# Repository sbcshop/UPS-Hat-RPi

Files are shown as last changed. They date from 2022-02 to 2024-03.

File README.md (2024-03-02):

# UPS-Hat-for-Raspberry-Pi
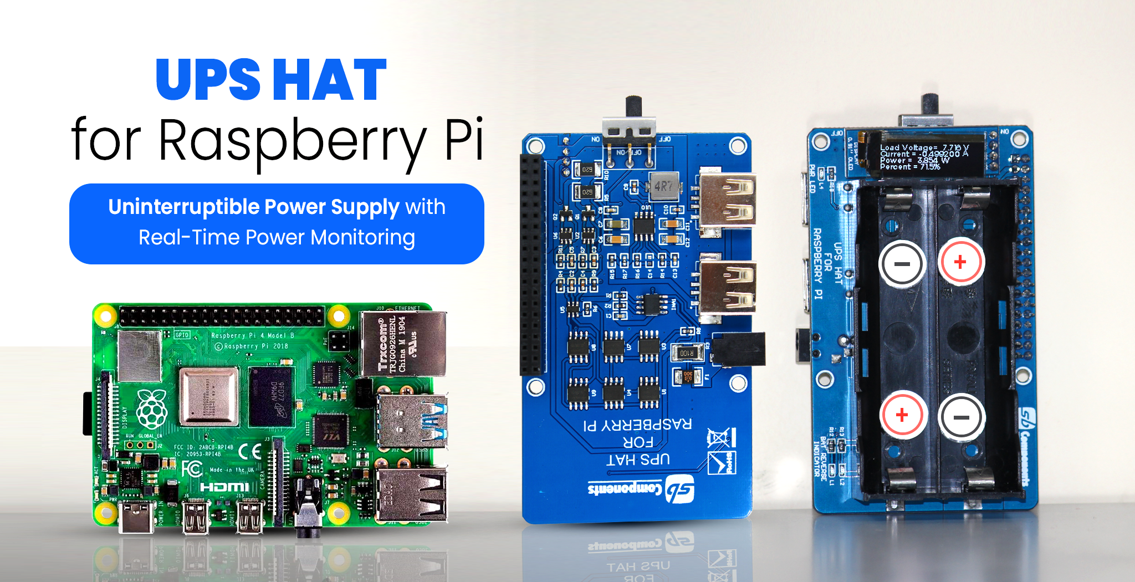
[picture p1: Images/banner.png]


## UPS Hat is a 5v power supply, It fit at the top of the raspberry pi, it gives power backup, while raspberry pi's USB power is cut off. It has various protections like short circuit protection, reverse battery protection and indicator, overcharge/discharge protection, and over current protection. It has a 5V USB output, convenient for powering other boards.
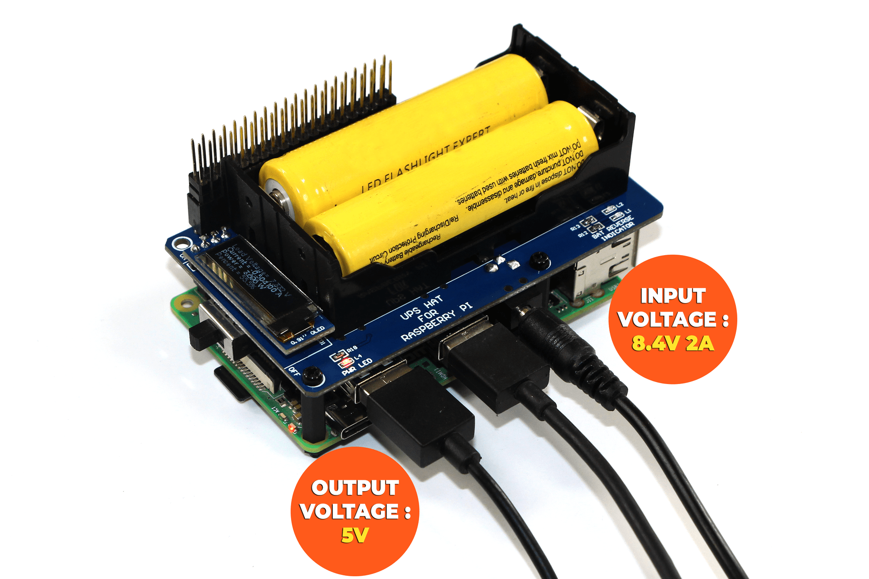
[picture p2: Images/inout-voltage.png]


## Features
  * Two on board battery reverse indicator Led's 
  * Two on board USB power port for external devices
  * Onboard oled display, for displaying current, voltage,power and battery percentage of UPS HAT
  * Onboard Battery Pack Protection and Charge Balance IC 

## Specification:-
- **Output voltage :** 5V USB 
- **Charger :** 8.4V 2A (Recommended)
- **Commuincation :** I2C 
- **Power monitoring IC :** INA219
- **Battery Supported :** 18650 Li Battery
- Display=>
 	* **Type** : OLED
 	* **Screen Size** : 0.91"
 	* **Resolution** : 128x32 pixels
 	* **Color** : Monochrome
	 * **Interface** : I2C
    
## Code
### First of all, you need to enable I2C in raspberry pi, for this you need to go  ```sudo raspi-config ``` then go to "interface options->I2C->yes->press enter" 
### This folder contains two python files and Images, Fonts folder:-
   * **INA219_UPS.py**  -> This file you need to run, displays the load voltage, current, power, and battery percentage on the terminal as well as in OLED
   * **oled_091.py**    ->This is the OLED display library 
   * **Images folder** contains images which we display in OLED display
   * **Fonts folder** contain various fonts, which we use in the OLED display
   
## Steps To Use UPS HAT (Follow These Steps) (**Important** *)
### Connect the type c power to the raspberry pi first, then turn on the UPS HAT, then disconnect the type c power from the raspberry pi or turn off the raspberry pi external power (at this time raspberry pi restart due to sudden power drop)Then reconnect the type c power to the Raspberry Pi after that ( In this process your raspberry pi needs to restart one time if you use UPS backup), The Raspberry Pi now does not restart if the type c power is turned off or if the external power is turned off.
### You need to follow this process when you use UPS HAT. if you use this process, your OLED problem is also resolved(static noise pattern)

  * Fix UPS HAT at the top of the Raspberry Pi
  
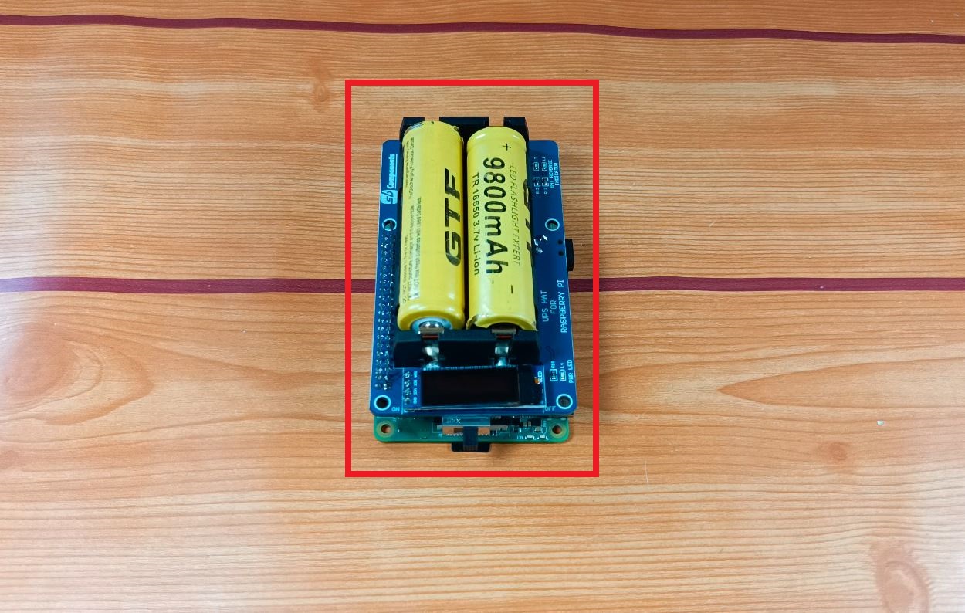
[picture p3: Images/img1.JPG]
    
   
  * Plug the Power cable to raspberry pi

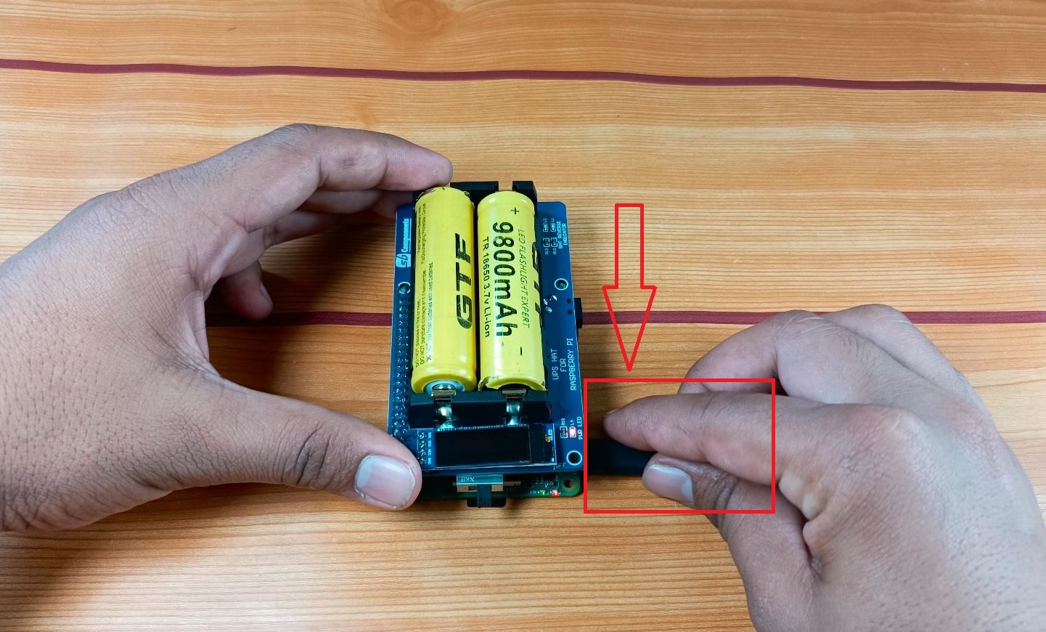
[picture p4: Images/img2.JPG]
    
    
  * Now Switch on UPS HAT using slider switch,then disconnect the type c power from the raspberry pi or turn off the raspberry pi external power (at this time             raspberry pi restart due to sudden power drop)Then reconnect the type c power to the Raspberry Pi after that ( In this process your raspberry pi needs to restart       one time if you use UPS backup)
  
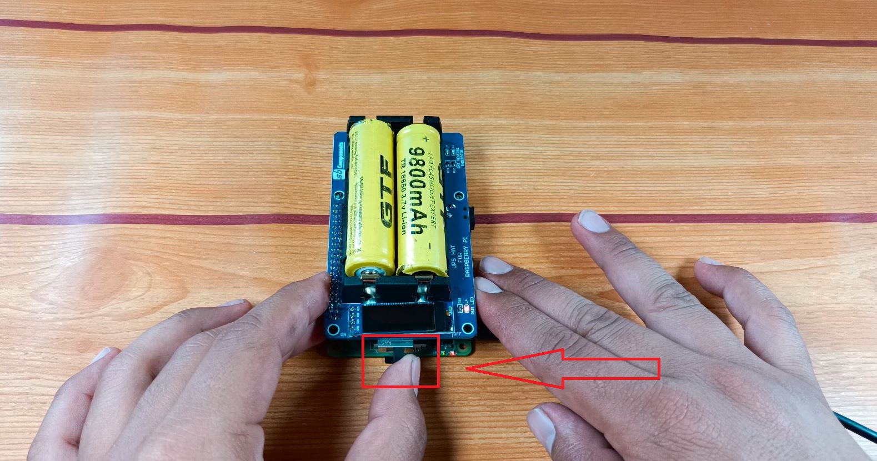
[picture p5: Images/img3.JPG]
    
    
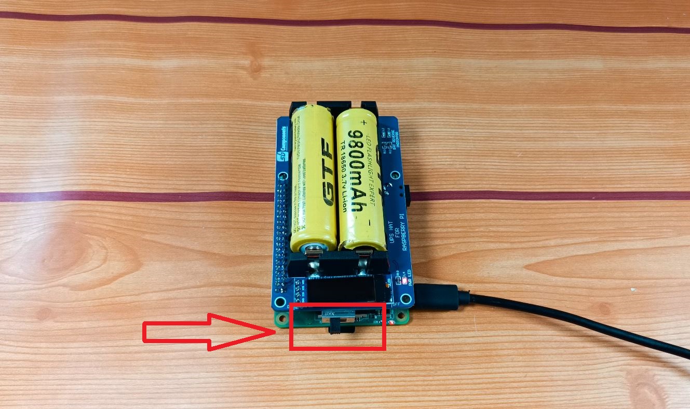
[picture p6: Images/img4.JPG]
    
    
    **Disconnect the external power**
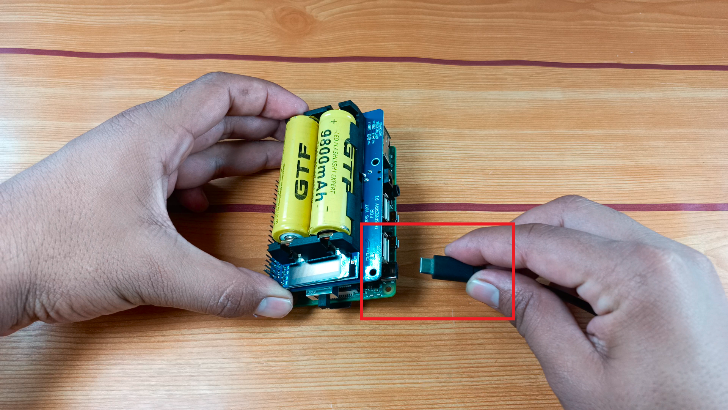
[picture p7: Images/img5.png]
    
    
    **Reconnect the external power**
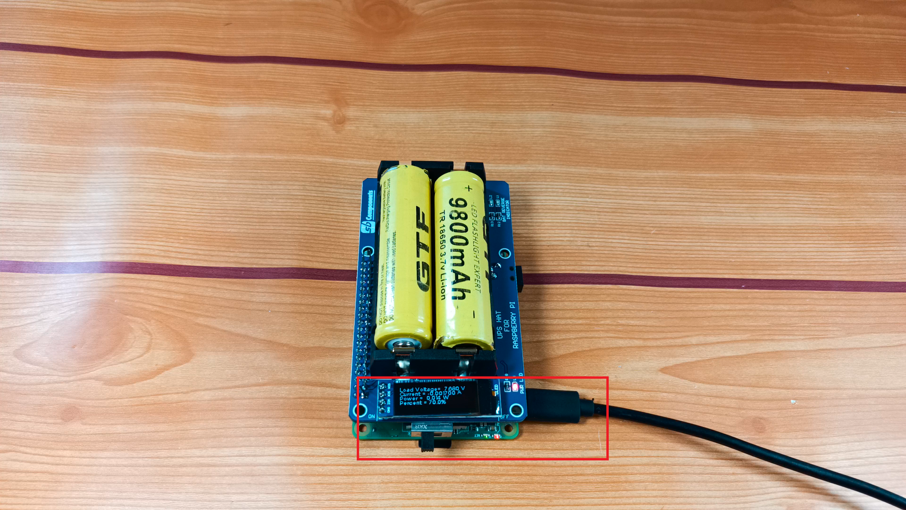
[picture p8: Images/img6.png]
    

## Run a Program On Your Raspberry Pi At Startup (*optional)
Go to below directory

 ```sudo nano /etc/rc.local```
 
 ```sudo python3 /home/pi/UPS-Hat-RPi/INA219_UPS.py &```
 
 <img src= "https://github.com/sbcshop/UPS-Hat-for-Raspberry-Pi/blob/main/Images/img_1.JPG" />
 
 Press Control+X then press Y to save

## Working
<img src= "https://github.com/sbcshop/UPS-Hat-for-Raspberry-Pi/blob/main/Images/giff.gif" />

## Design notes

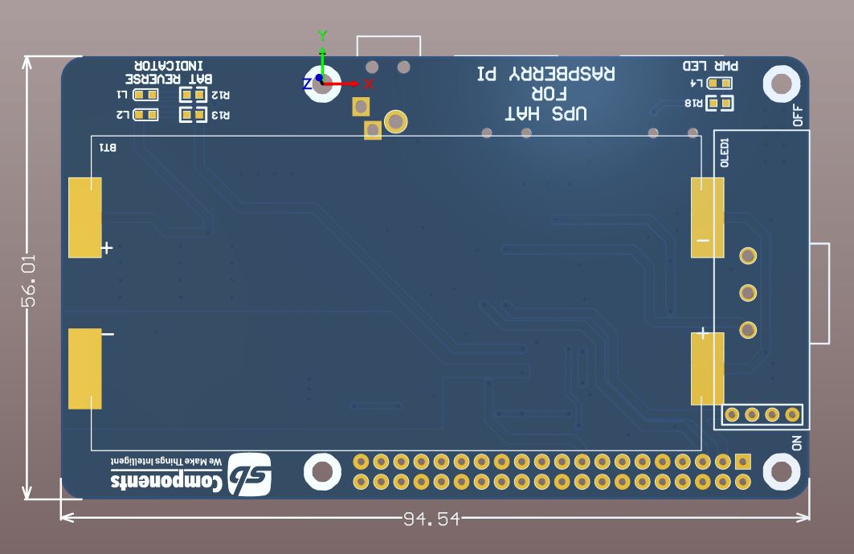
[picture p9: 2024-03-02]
Design Data/Top View.JPG

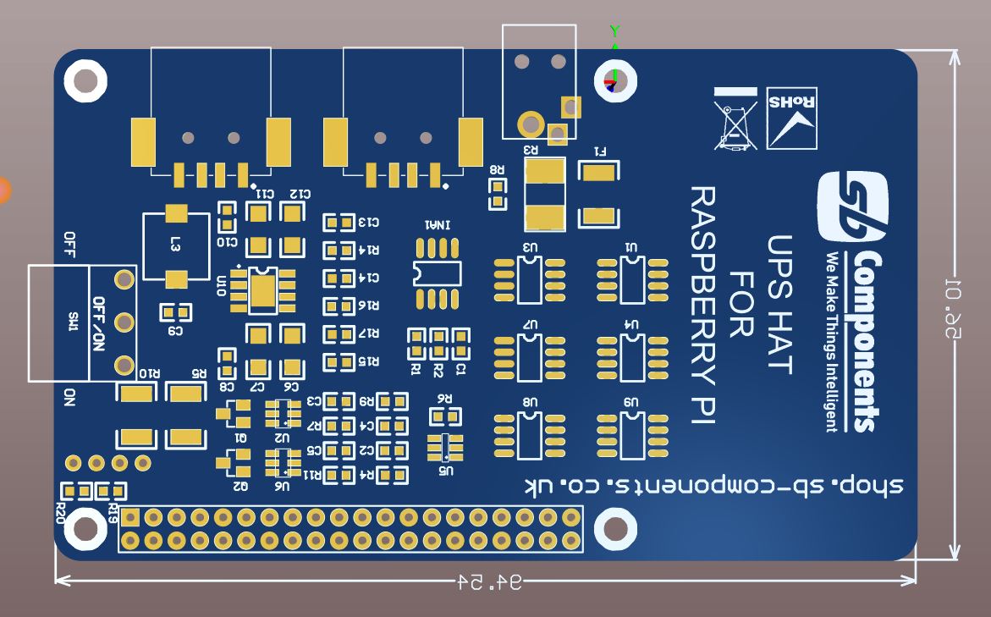
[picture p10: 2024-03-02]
Design Data/Bottom View.JPG

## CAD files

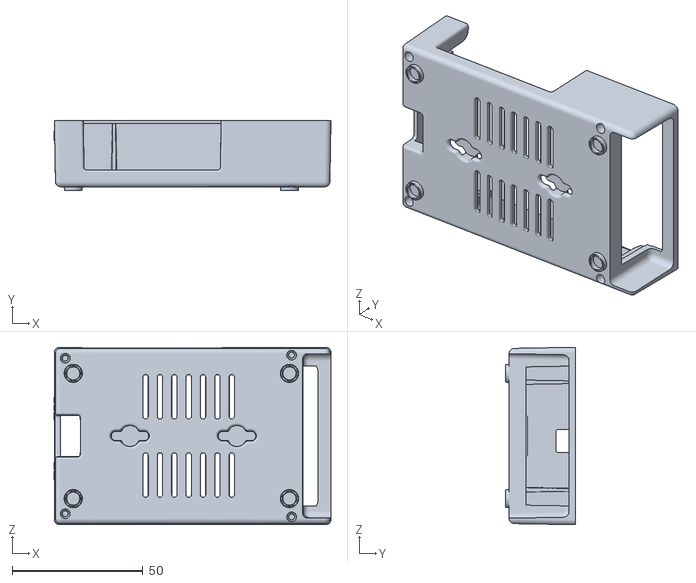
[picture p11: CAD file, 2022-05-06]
UPS_Bottom_Cover.STL
106.1 x 27.0 x 68.0

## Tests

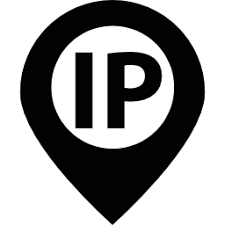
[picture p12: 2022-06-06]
Test_oled/Images/IP.png

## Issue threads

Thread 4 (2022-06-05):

Display not working

pbhound, 2022-06-05:
I have followed the instructions but I am not able to get the display on the UPS hat to work.

any Ideas?

sbcshop1, 2022-06-06:
@pbhound
First, you need to check individually whether OLED is working or not, for this switch off the UPS HAT, and stack it to a raspberry pi. And In this repository, we upload a folder, name "Test_oled", inside this folder, there is a file name "main.py", kindly run this file, this file run the OLED screen.

whab, 2022-06-10:
I'm also encountering an issue with the OLED which displays on occasion a static noise pattern as shown on the attached screenshot below:
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
This did not occur at first, but after adding the following line to /etc/rc.local and restarting the Pi:

    sudo python3 /home/pi/Desktop/UPS_Hat/INA219_UPS.py &

The only way I found to recover the display functionality is to power off the Pi, remove the batteries from the UPS Hat, and power the Pi 4 through USB-C. Then the Test_oled/main.py example works just fine. However, even after re-installing the batteries on the UPS hat and restarting with the UPS Hat as the only source of power, the display still shows the static noise pattern... From there, to get the display to run on UPS Hat power again was to reconnect the main power through USB-C (with the UPS Hat also turned on), power down, and disconnect the main power. This triggers a restart, but then the display seems to work again. However the same issue re-occurs each time I power the Pi with the UPS Hat...

Also my Pi 4 restarts when unplugging its main power (USB-C) with the UPS Hat attached to it: is it the expected behavior???  The Kickstarter campaign page explicitly says: “An uninterruptible power supply (UPS), also known as a battery backup, provides backup power when your regular power source fails or voltage drops to an unacceptable level.”. So the actual  behaviour on my device does not seem right as I would expect the UPS Hat to take over when the main power source stops...

sbcshop1, 2022-06-10:
It is caused by a power drop at the Raspberry Pi, which can be caused by abruptly unplugging the type C cable or turning off the power. This is a common occurrence with this device. To avoid this problem, connect the type c power to the raspberry pi first, then turn on the UPS HAT, then disconnect the type c power from the raspberry pi or turn off the raspberry pi external power (at this time raspberry pi restart due to sudden power drop)Then reconnect the type c power to the Raspberry Pi after that ( In this process your raspberry pi needs to restart one time if you use UPS backup), The Raspberry Pi now does not restart if the type c power is turned off or if the external power is turned off.
You need to follow this process when you use UPS HAT. if you use this process, your OLED problem is also resolved(static noise pattern)

whab, 2022-06-10:
This seems to fix the issue. It would be useful to properly document this... Thanks!

GeekyTim, 2023-02-19:
This method has worked once or twice, but not reliably.  Can you please provide a proper solution which will reset the i2c bus?

GeekyTim, 2023-02-19:
I just got it working for a few minutes, monitoring the UPS service I have written which monitors the battery status and powers it down if it gets too low - as well as writing to the screen. While in use - i.e. working, no reboot, it failed with a connection timeout:

Feb 19 17:35:17 InfluxPi python3[970]: Traceback (most recent call last):
Feb 19 17:35:17 InfluxPi python3[970]:   File "/home/geekytim/UPS/ups.py", line 16, in <module>
Feb 19 17:35:17 InfluxPi python3[970]:     attachedups = ups.UPS()
Feb 19 17:35:17 InfluxPi python3[970]:   File "/home/geekytim/UPS/upscode/sbcomponents.py", line 69, in __init__
Feb 19 17:35:17 InfluxPi python3[970]:     self.__oled_display = SSD1306()
Feb 19 17:35:17 InfluxPi python3[970]:   File "/home/geekytim/UPS/upscode/oled_091.py", line 96, in __init__
Feb 19 17:35:17 InfluxPi python3[970]:     self.__InitDisplay()
Feb 19 17:35:17 InfluxPi python3[970]:   File "/home/geekytim/UPS/upscode/oled_091.py", line 126, in __InitDisplay
Feb 19 17:35:17 InfluxPi python3[970]:     self.__WriteCommand(DISPLAY_ON)
Feb 19 17:35:17 InfluxPi python3[970]:   File "/home/geekytim/UPS/upscode/oled_091.py", line 120, in __WriteCommand
Feb 19 17:35:17 InfluxPi python3[970]:     self.i2c_write(register=0x00, data=cmd)
Feb 19 17:35:17 InfluxPi python3[970]:   File "/home/geekytim/UPS/upscode/oled_091.py", line 75, in i2c_write
Feb 19 17:35:17 InfluxPi python3[970]:     self.bus.write_byte_data(self.address, register, data)
Feb 19 17:35:17 InfluxPi python3[970]: TimeoutError: [Errno 110] Connection timed out
Feb 19 17:35:17 InfluxPi systemd[1]: UPS.service: Main process exited, code=exited, status=1/FAILURE

GeekyTim, 2023-02-20:
And overnight it stopped. I'm now going to try and run without the display to see if that helps.

sbcshop1, 2023-02-21:
@GeekyTim Could you please share your code with me so that I can assist you?

GeekyTim, 2023-02-21:
I have uploaded the code to here: https://github.com/GeekyTim/UPSControl

I left this code running (with the screen code commented out) and the UPS performed as expected. I did get some warnings that the Pi was on battery from time to time, but that was because I have not yet fine tuned the code that informs me whether power is connected yet - I made some estimates on simple testing at the start.

GeekyTim, 2023-02-25:
Weirdly, I _might_ have stumbled on a reason for one of the issues I am experiencing with this UPS - not definitive, but a possibility.  This concerns the i2c timeouts I am experiencing (TimeoutError: [Errno 110] Connection timed out).

I have created a case for the Pi/UPS and SSD (see below). It is quite a tight fit. The lid pulls the sides in against the sides of the UPS and Pi. With the lid off, all is okay. When I put the lid on, I get the i2c timeout issue. I take the lid off, and the i2c comes back to life (slowly) - the timeout (TimeoutError: [Errno 110] Connection timed out) is replaced with an input/output error (OSError: [Errno 5] Input/output error), and then the UPS software starts correctly again (using systemd).

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

I think I need to re-make the case with more tolerance.

This does not explain the 'speckled' screen issue.

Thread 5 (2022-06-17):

External power-supply vs Pi USB-C power

tillik, 2022-06-17:
My UPS-hat seems to work as expected, but unfortunately I find the documentation a little sparse.
How is the Power supply supposed to work? Will the batteries also be charged when the Pi is powered via USB-C?
Or do I need to use the external power-supply for this?
What happens if I connect both the USB-C power-supply of the Pi and your external power-supply?

tillik, 2022-06-21:
You [Youtube-Video ](https://www.youtube.com/watch?v=9vatnF2JgK8) shows charging the batteries using the external power-supply. What if someone accidentally connects both the Raspberry USB-C power as well as the external power-supply?

tedder, 2022-06-25:
I was wondering this too. I assumed it only worked with the 8v power supply.

sbcshop1, 2022-07-04:
@tillik  What if someone accidentally connects both the Raspberry USB-C power as well as the external power supply?
answer - Nothing will happen if you connect both type-c power as well as an external 8v adapter to UPS HAT.Raspberry pi get only 5v

Closed 2024-08-12.

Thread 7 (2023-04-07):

RPI using python 3.9

dinnoc, 2023-04-07:
When i run test Oled or INA219_UPS.py i get the following error

No module Named 'PIL'

its seems PIL is deprecated for Pillow.  Can you fix this?

sbcshop1, 2023-04-10:
Yes, PIL means Pillow library, you need to install this library in raspberry pi, you can try following command "pip3 install Pillow"

Closed 2024-08-12.

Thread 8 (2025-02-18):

Can You Just Provide 8.2V power?

shawnerz, 2025-02-18:
I finally got around to using this UPS on a Pi4.

Hints: sudo apt install python3-pillow

Can I just power the the Pi4 and UPS from the 8.2V supply? In other words, is there a need to power the Pi4 with the 5V power supply?

Thanks,
-Shawn

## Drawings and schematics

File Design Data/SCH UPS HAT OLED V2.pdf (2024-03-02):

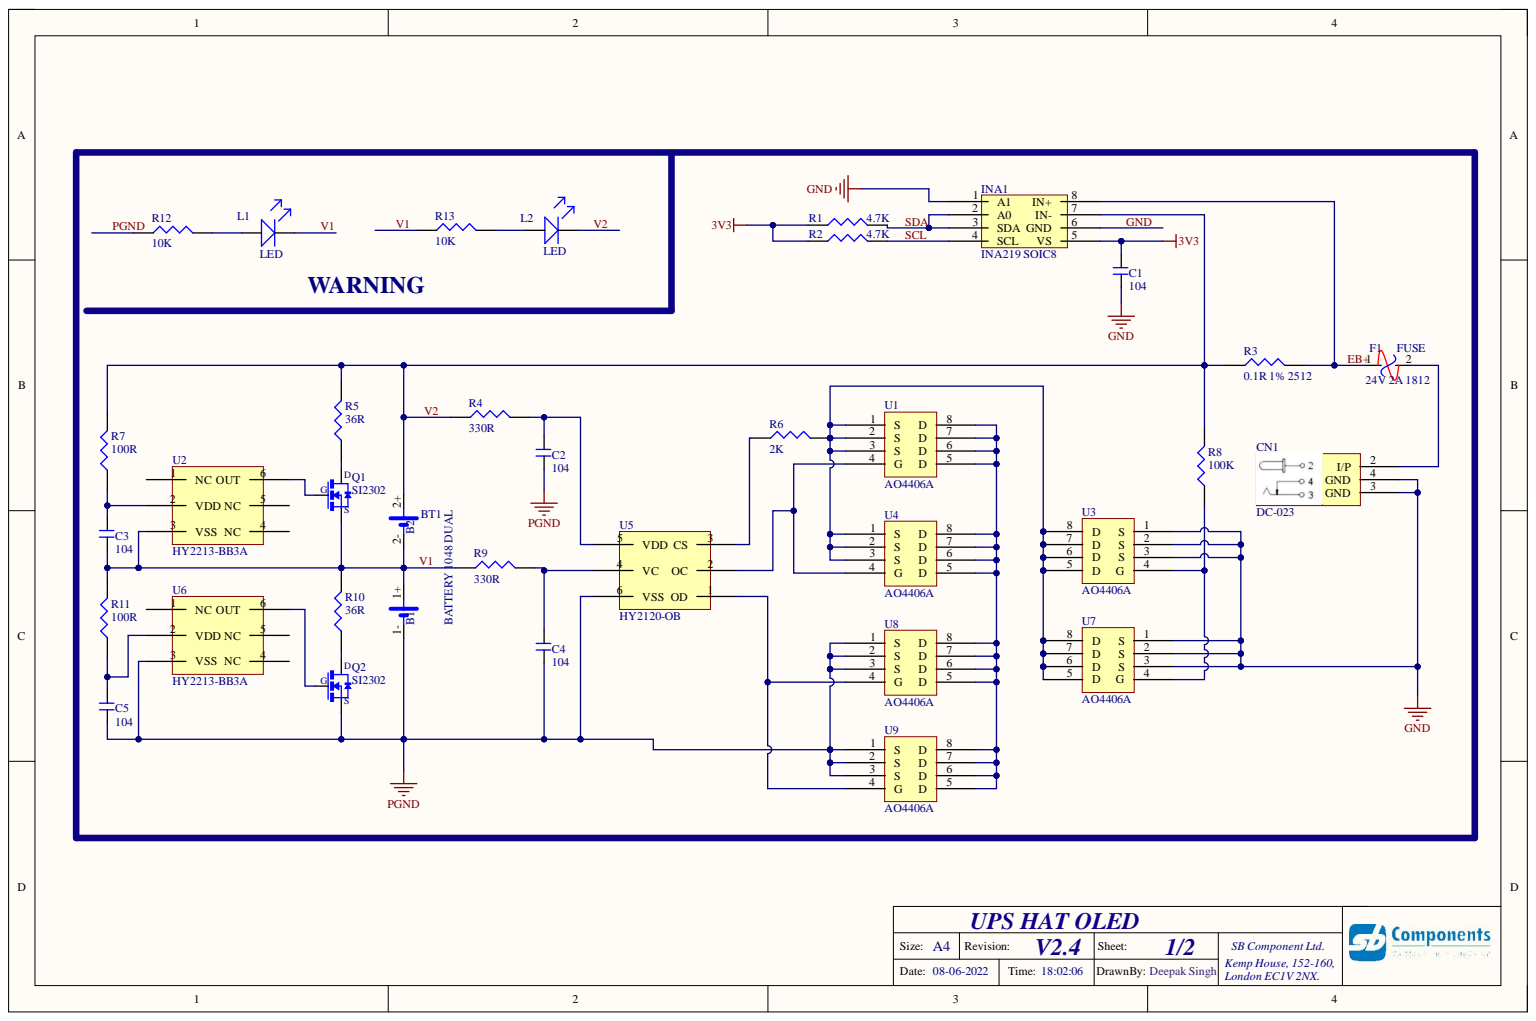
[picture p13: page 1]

2 | S D S D G D | 7

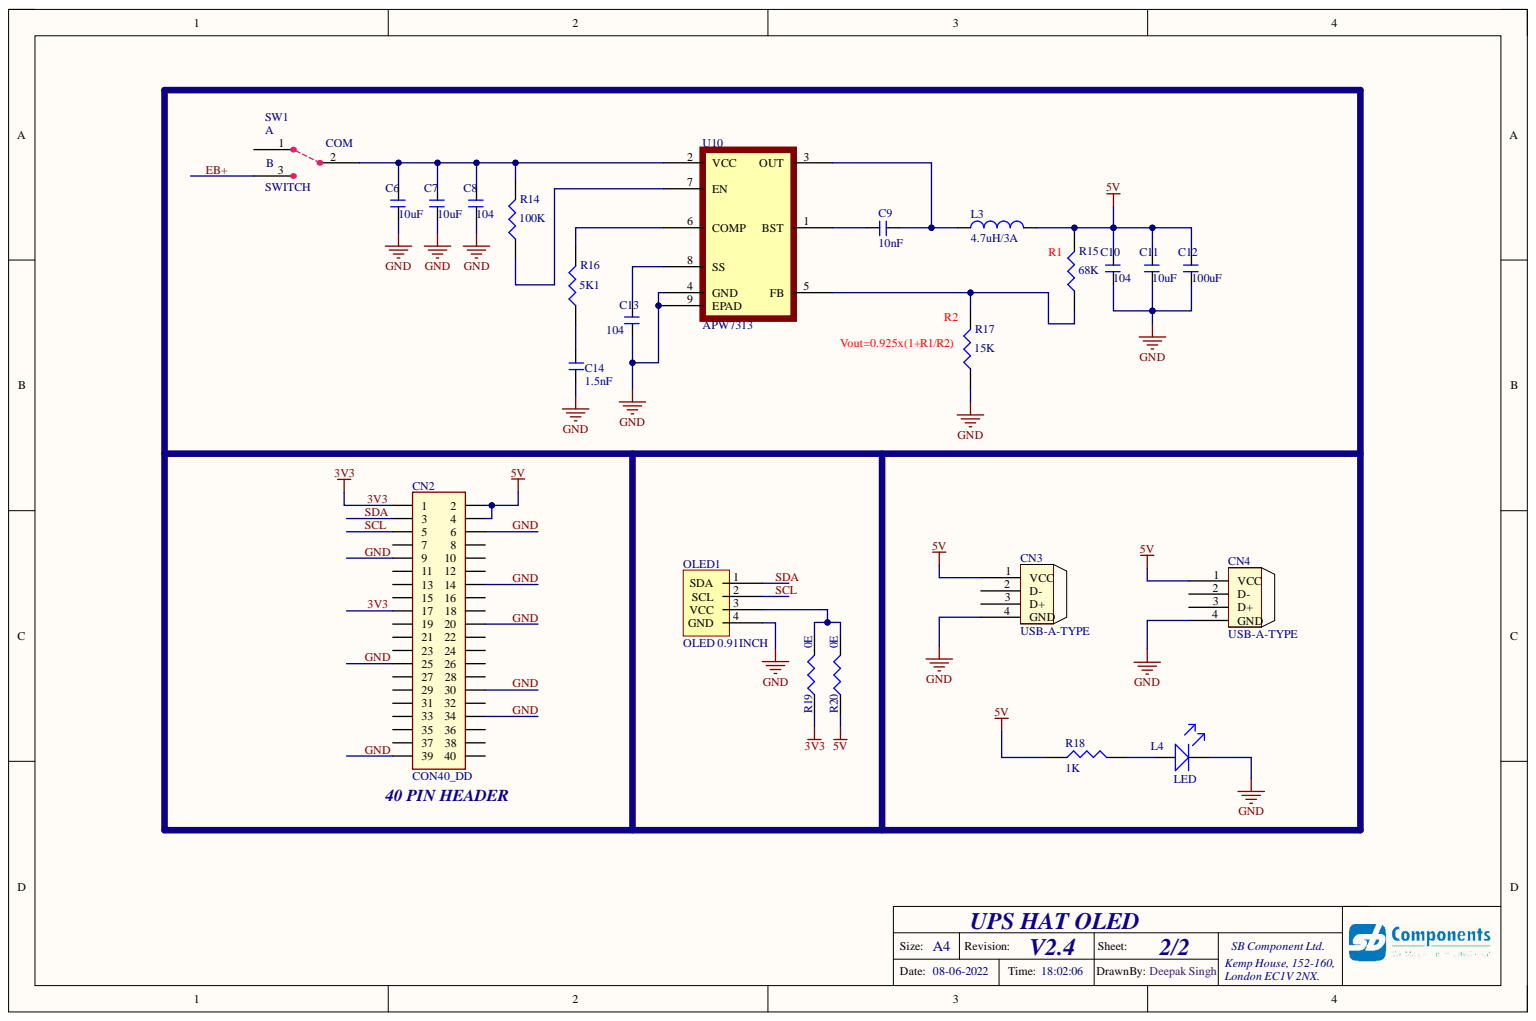
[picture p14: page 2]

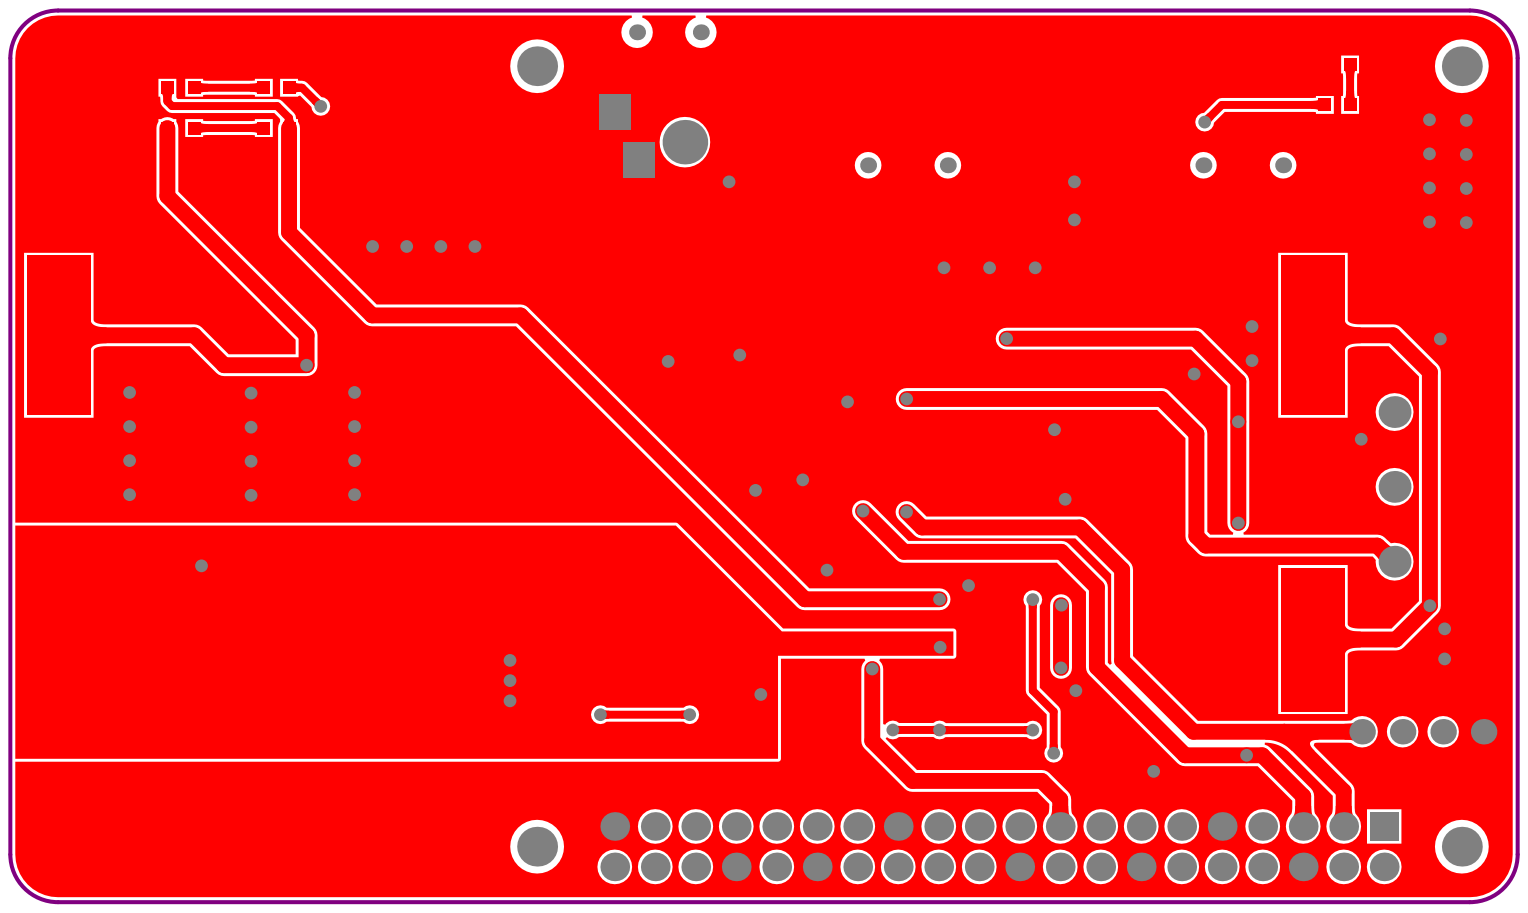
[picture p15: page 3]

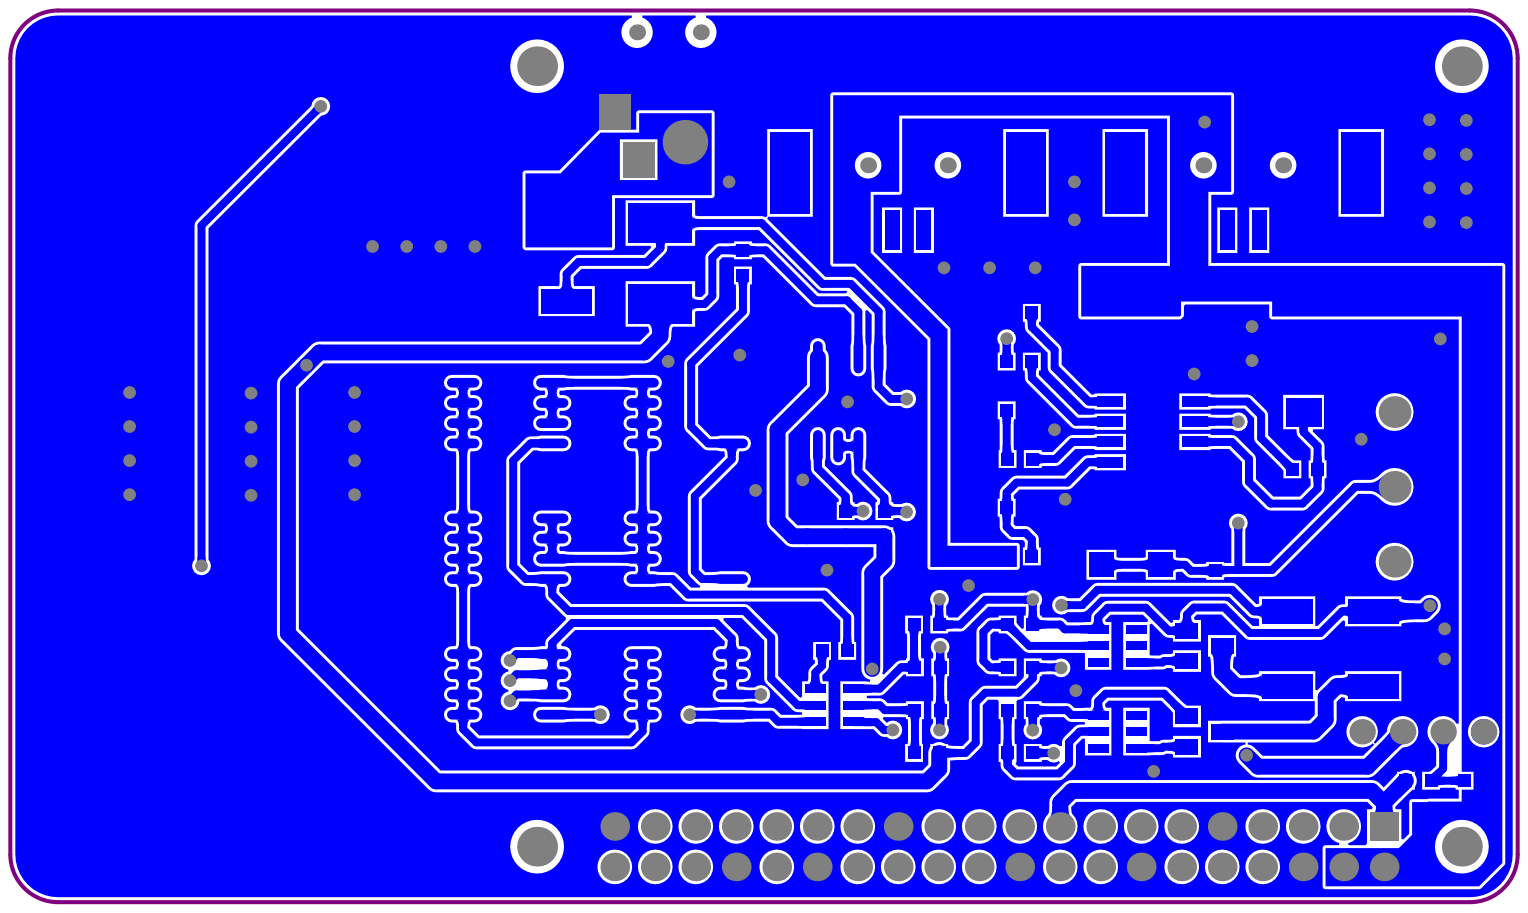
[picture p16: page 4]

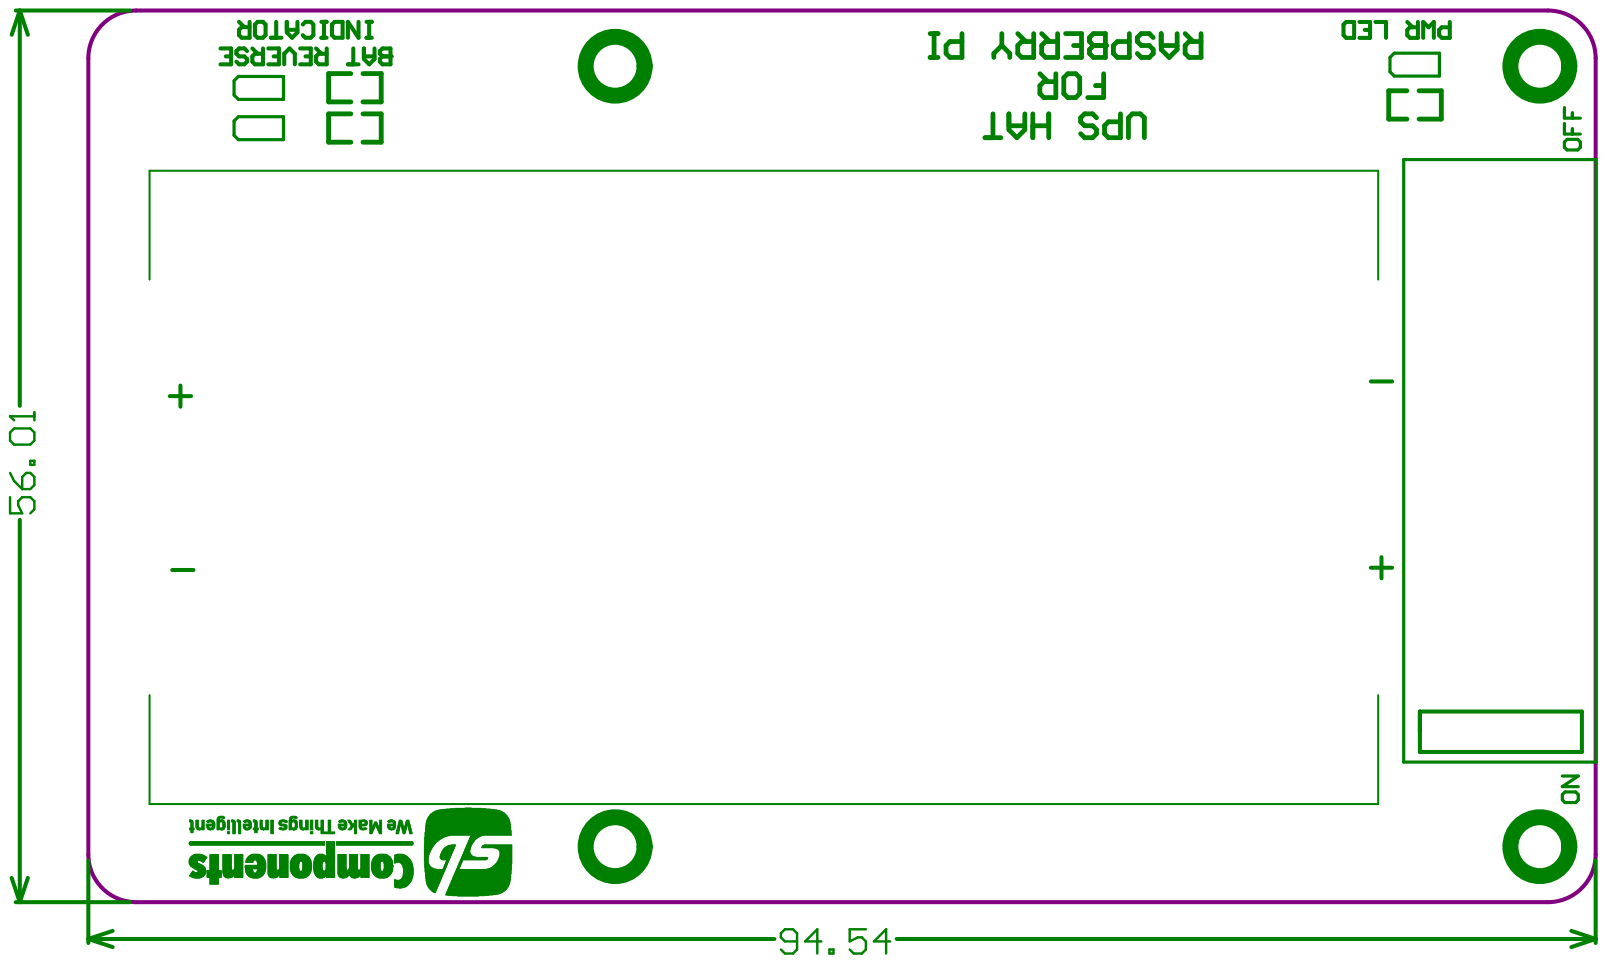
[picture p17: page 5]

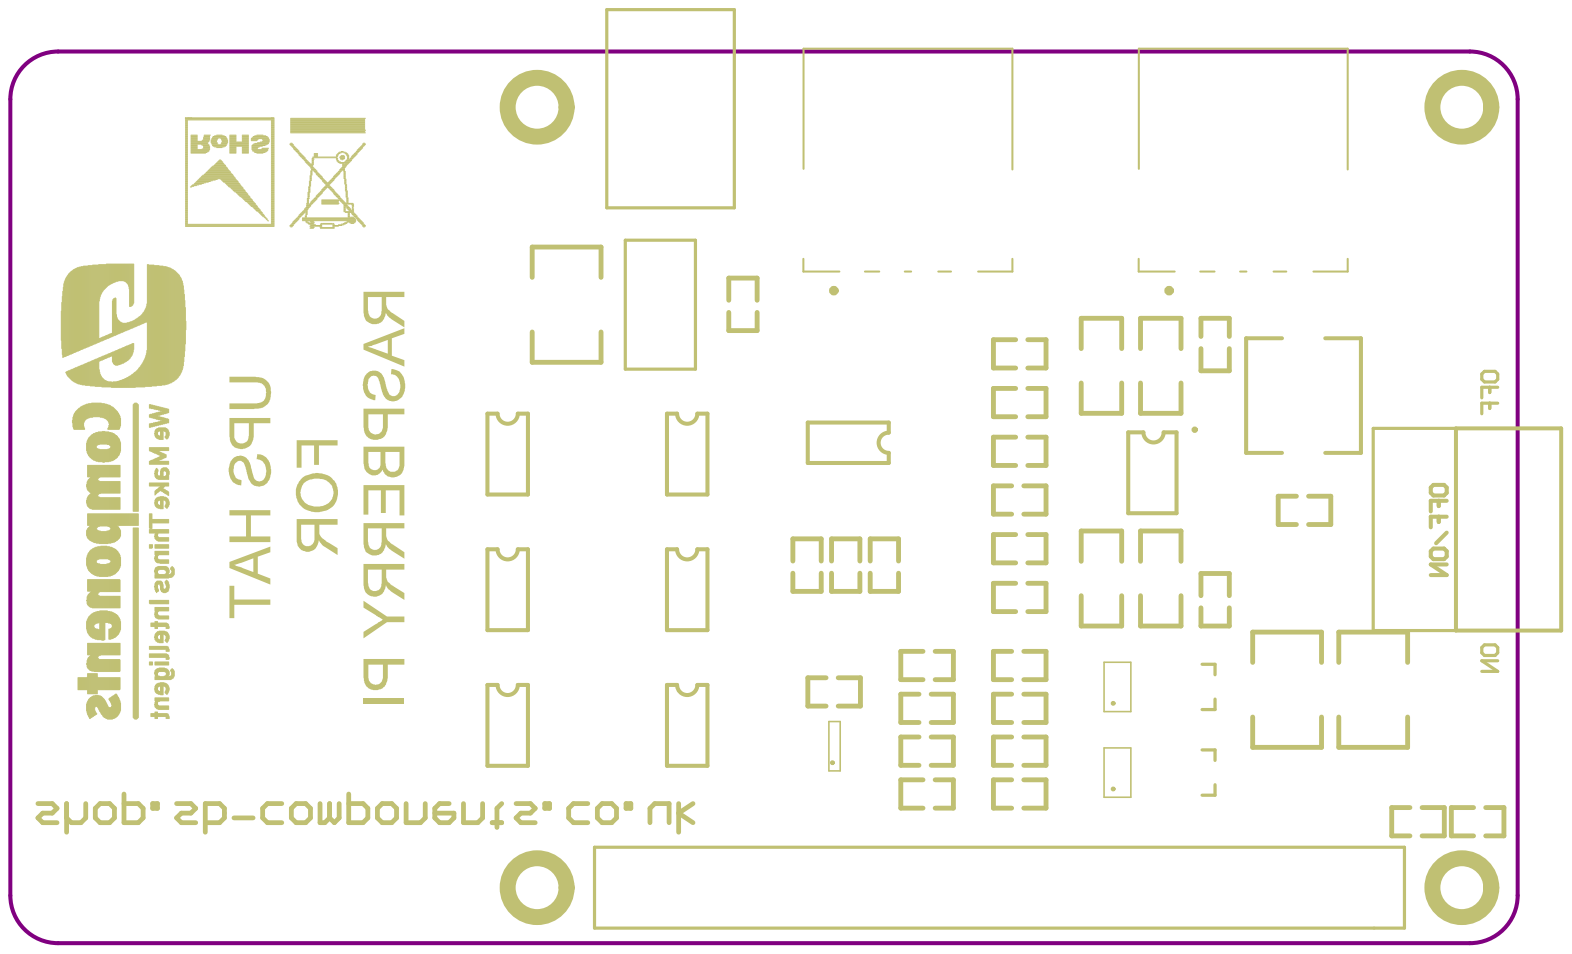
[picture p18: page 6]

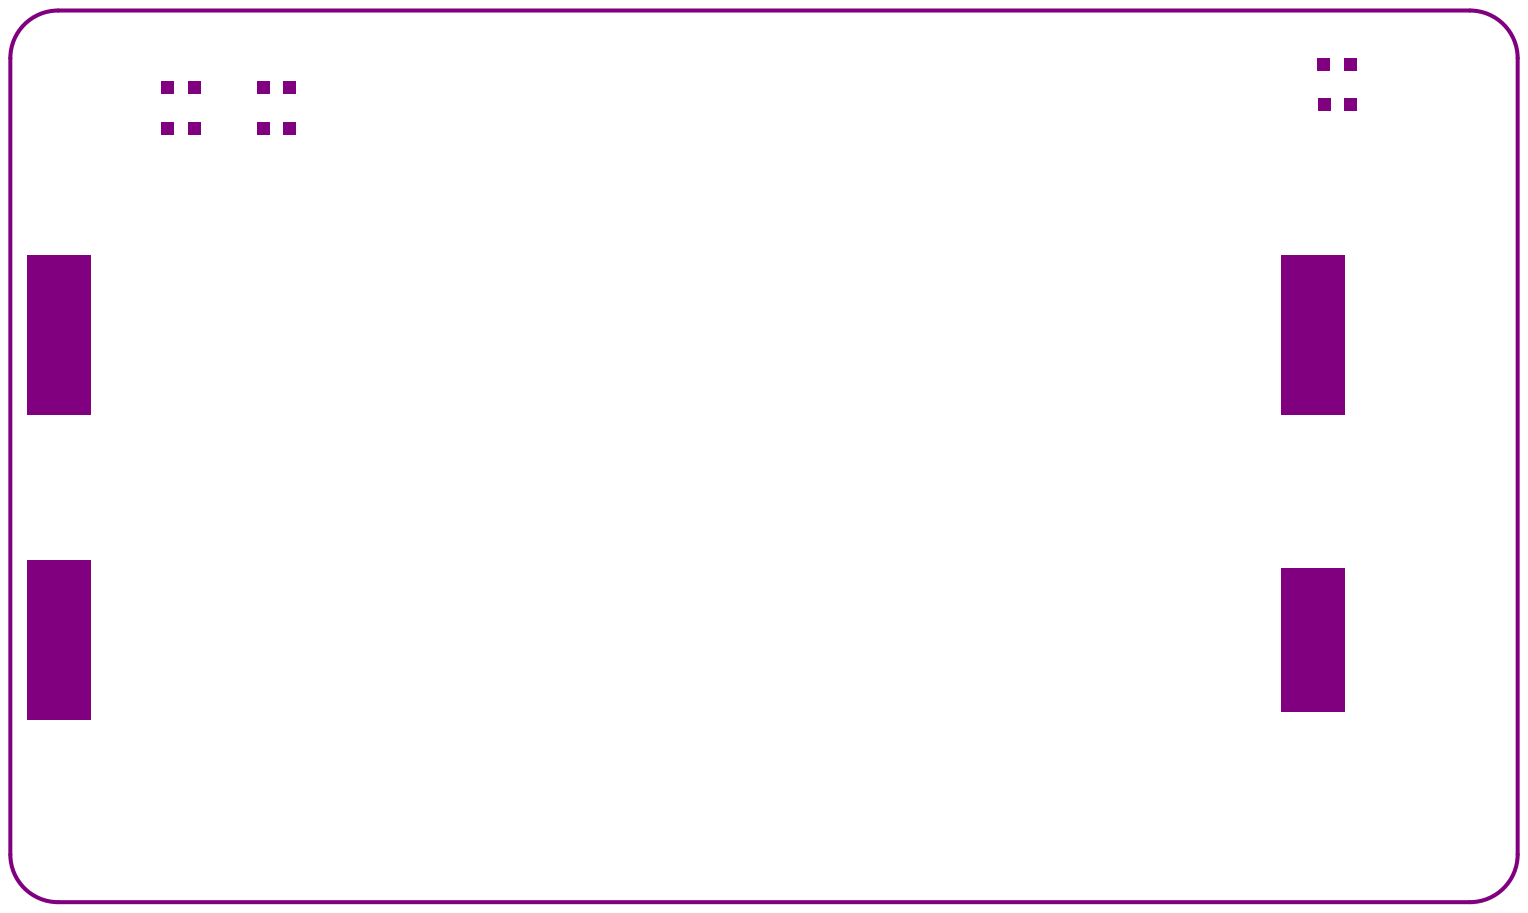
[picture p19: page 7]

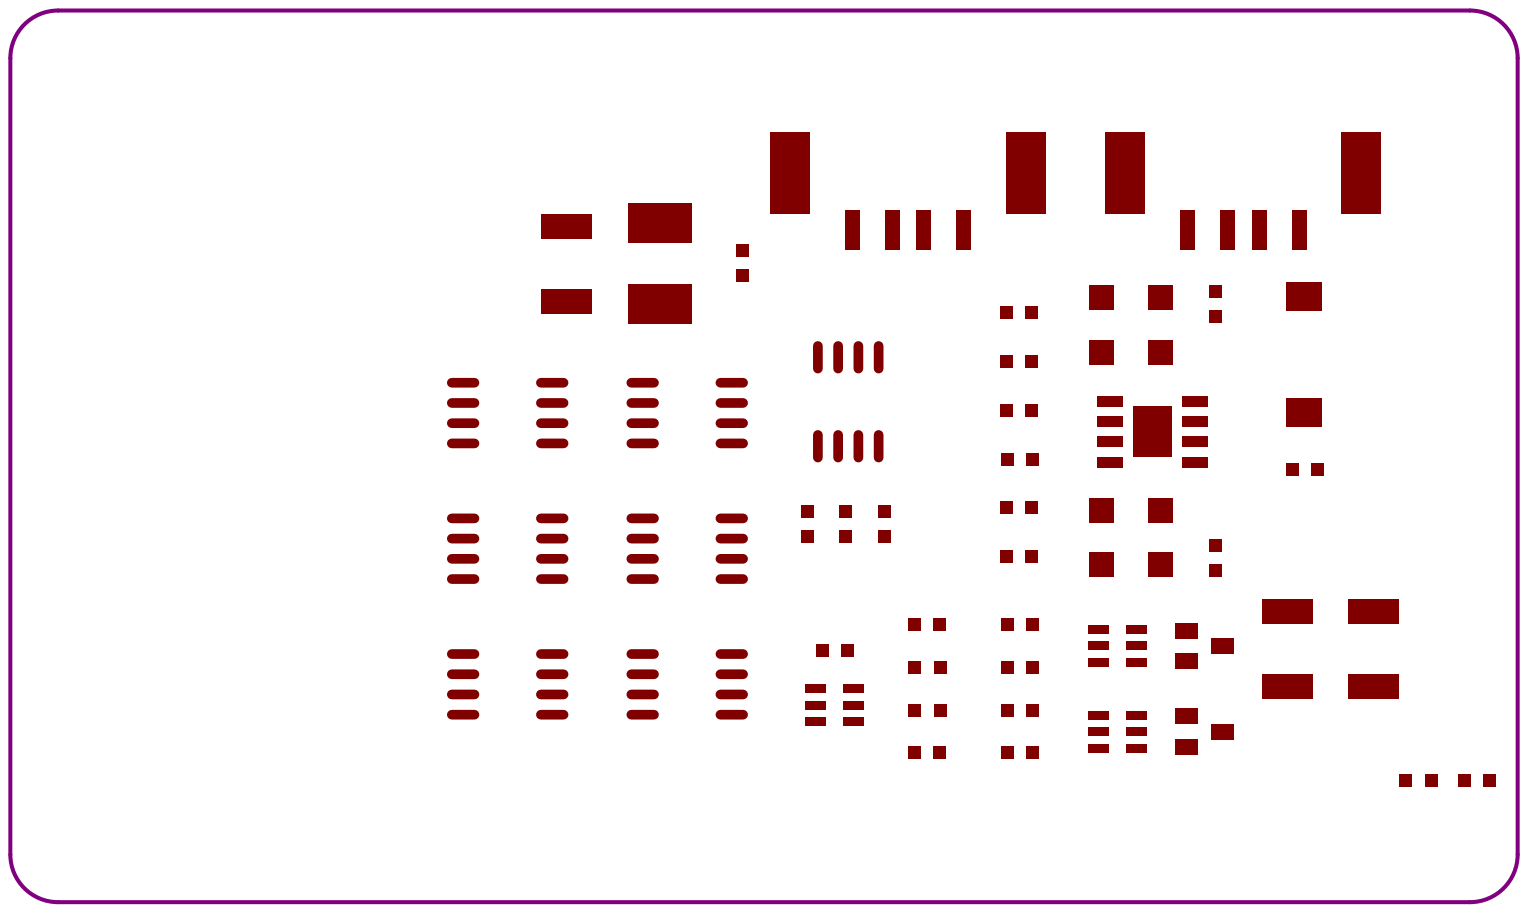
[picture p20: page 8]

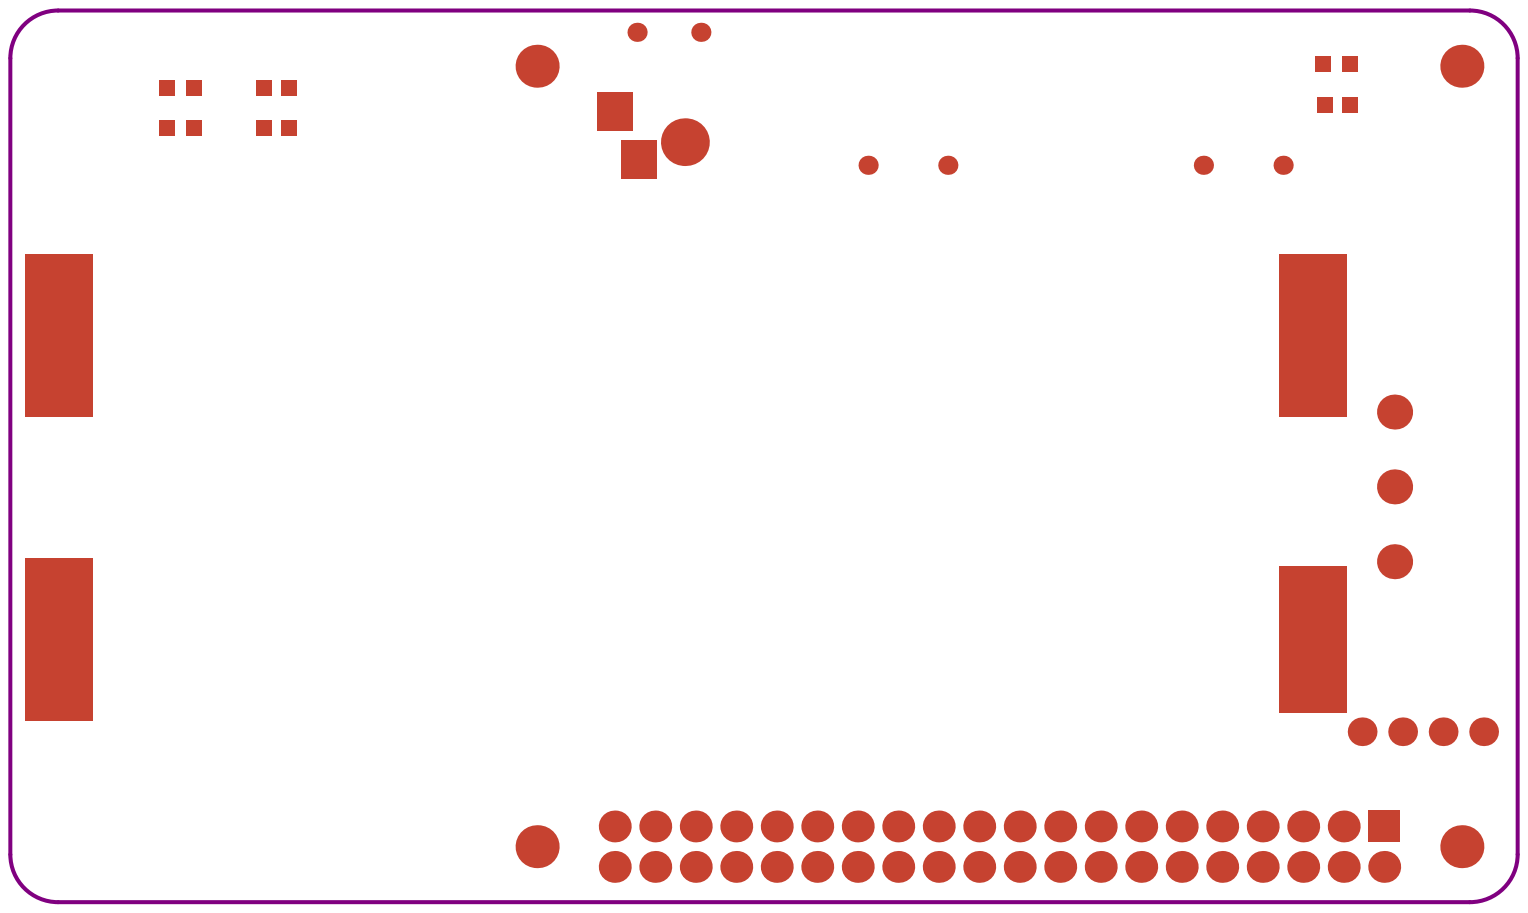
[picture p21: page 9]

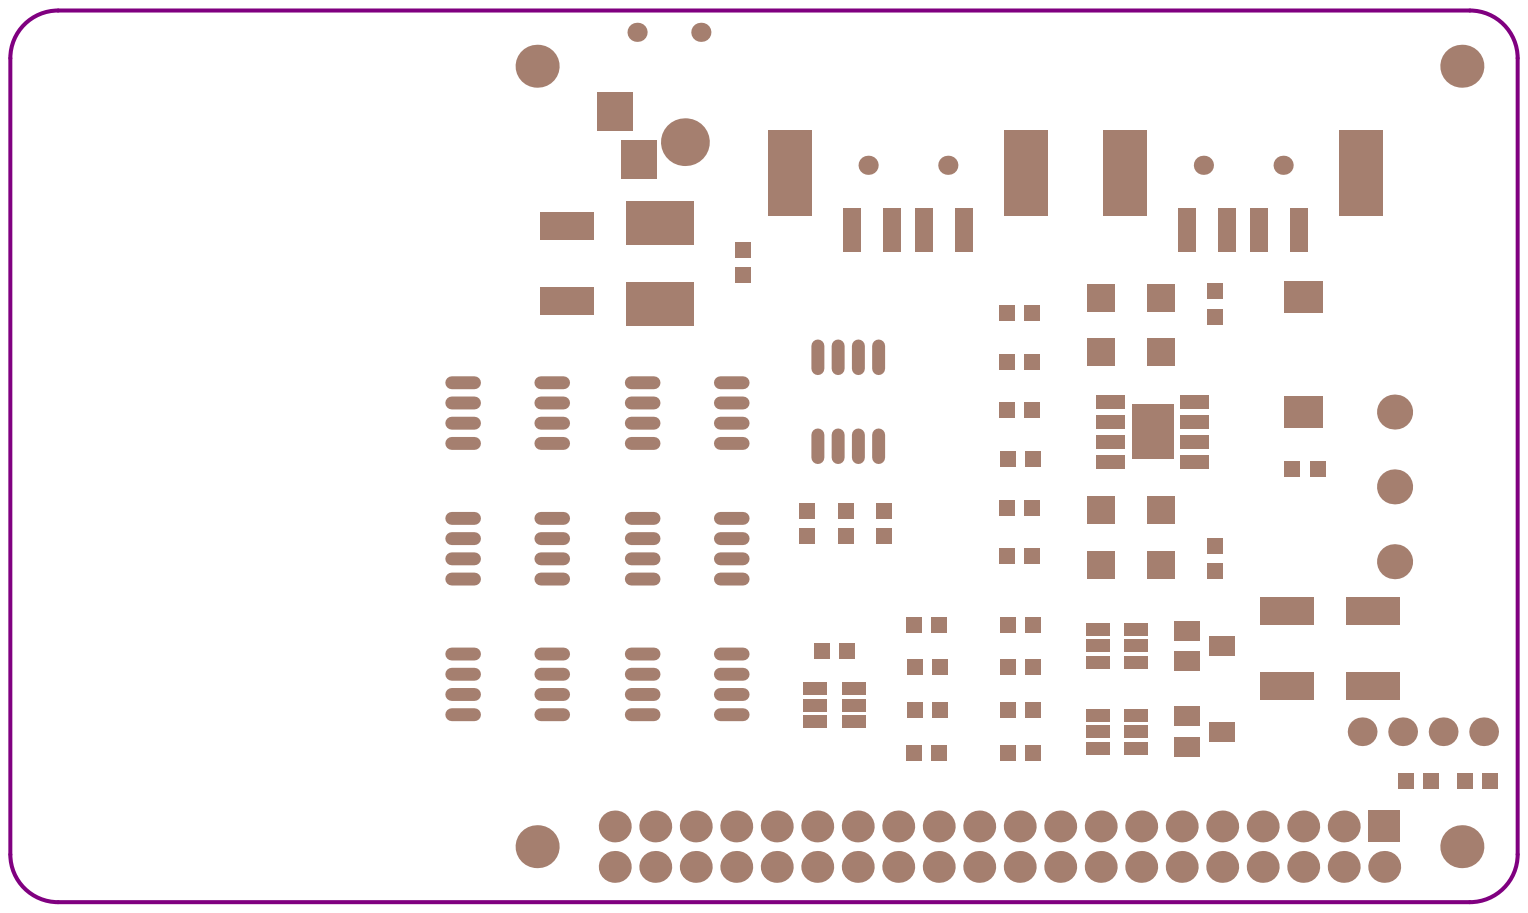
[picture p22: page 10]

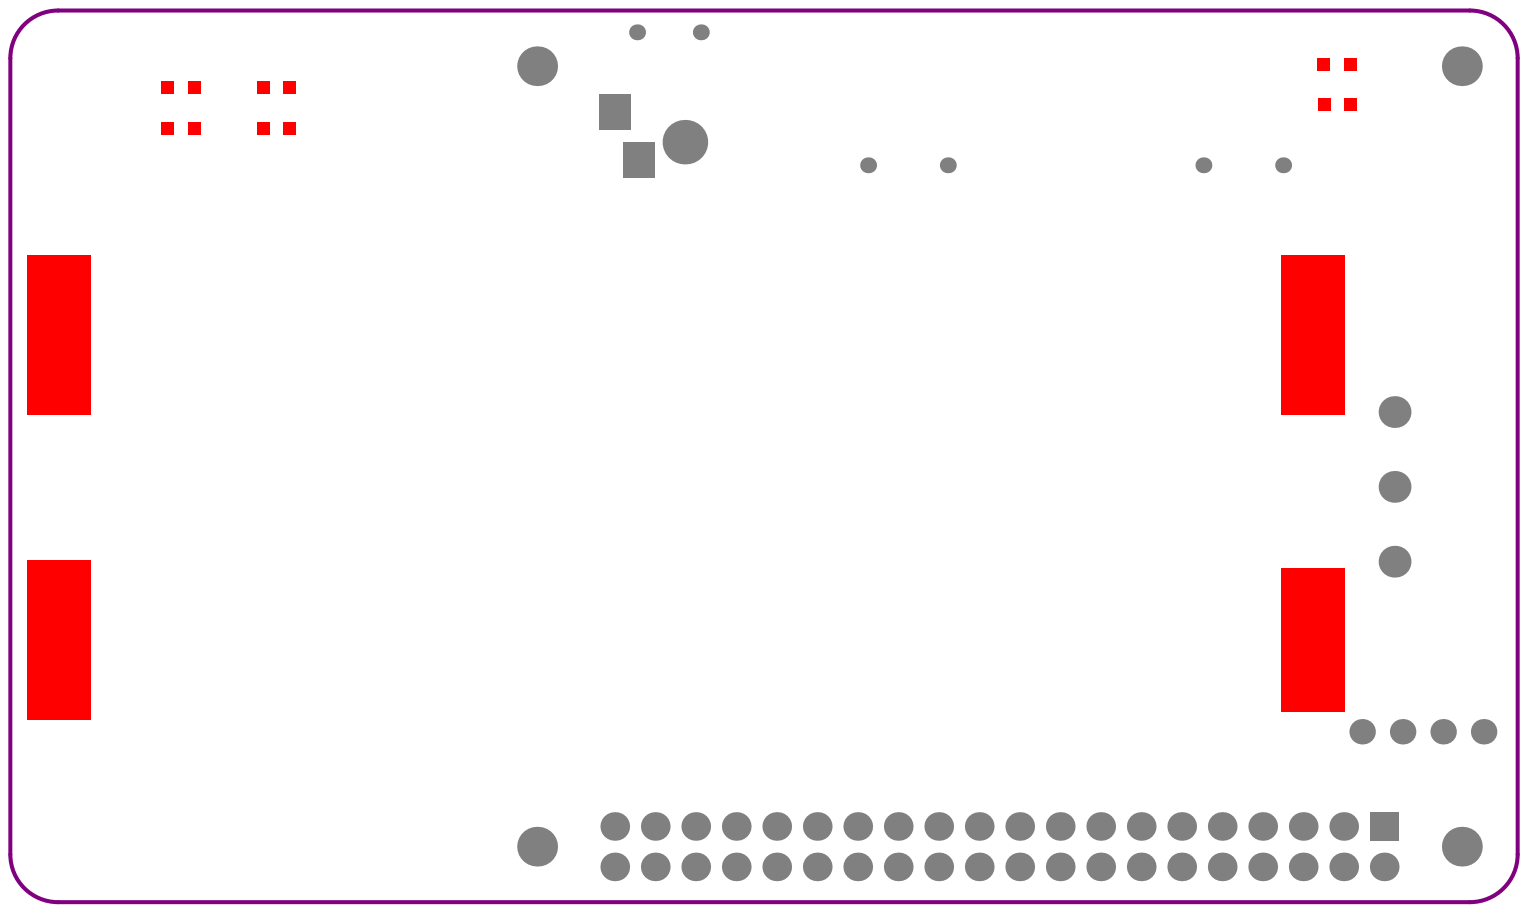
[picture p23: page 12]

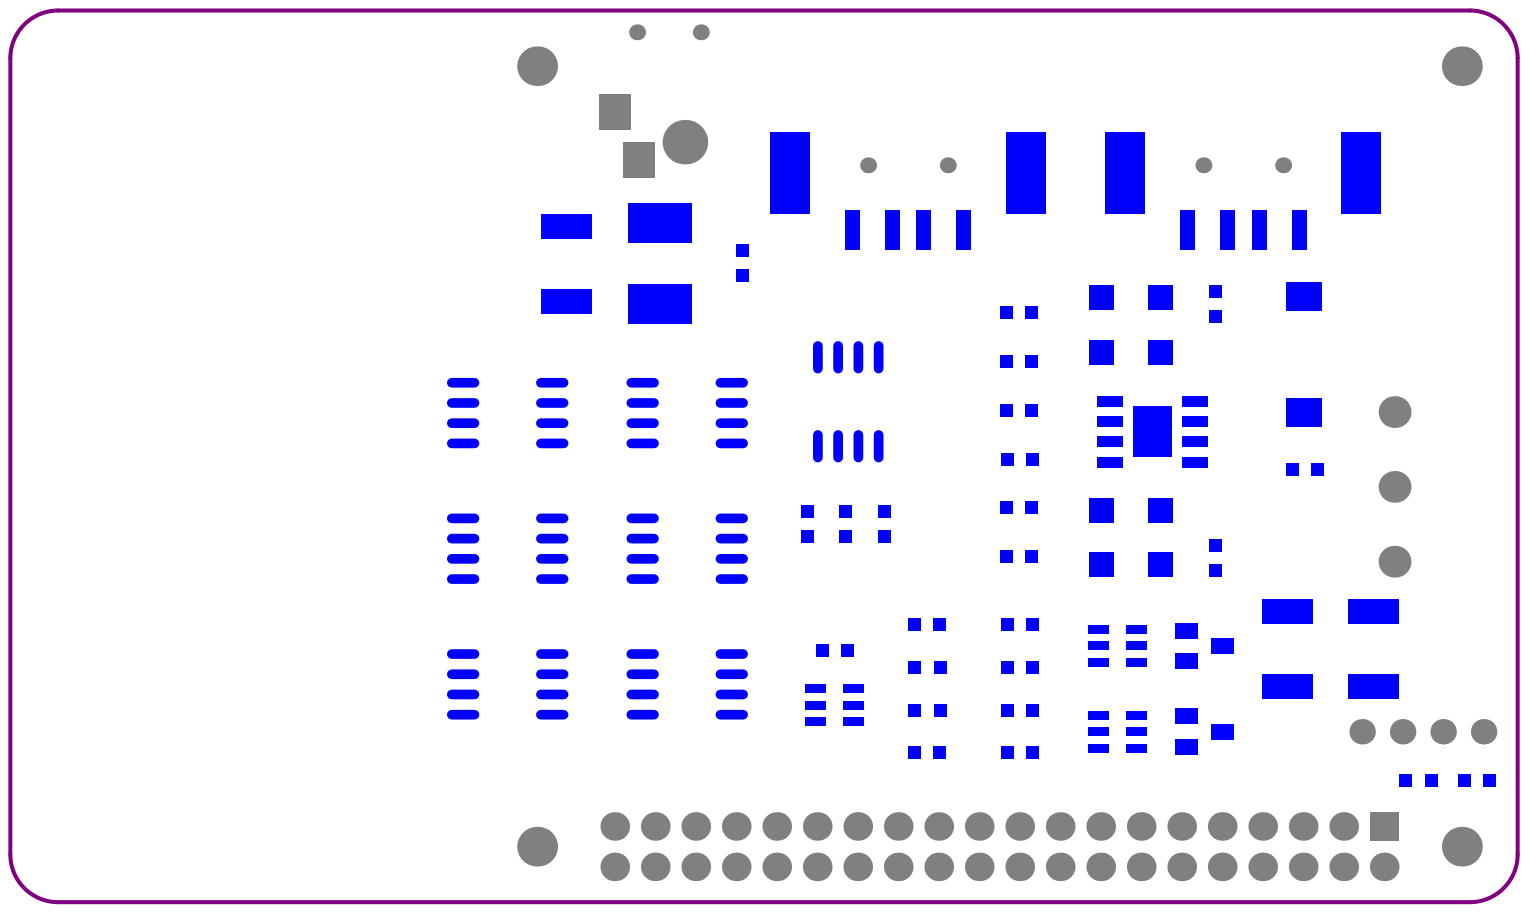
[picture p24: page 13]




Comment | Description | Designator | Footprint | LibRef | Quantity
BATTERY 1048 DUAL | RF EMI Absorbing Sheet Q-ZorbÂ® Silicone Rubber Non-Conductive, Single Sided 24.000 _609.60mm_ X 24.000 _609.60mm_ X 0.094 _2.40mm_ | BT1 | BAT_1048P SMD | BATTERY 1048 DUAL | 1
104 | | C1, C2, C3, C4, C5, C8, C10, C13 | CAP_0603_NONPOLA R | CAP_NONPOLAR | 8
10uF | | C6, C7, C11 | CAP_1206 | CAP_NONPOLAR | 3
10nF | | C9 | CAP_0603_NONPOLA R | CAP_NONPOLAR | 1
100uF | | C12 | CAP_1206 | CAP_NONPOLAR | 1
1.5nF | | C14 | CAP_0603_NONPOLA R | CAP_NONPOLAR | 1
DC-023 | DC-023 4.0mm x 1.7mm Black DC Power Jack Socket Connector needle DC Female Jack | CN1 | DC-023 | DC-023 | 1
CON40_DD | | CN2 | CON40_DD_2p5mm_ BOT | CON40_DD | 1
USB-A-TYPE | | CN3, CN4 | USB A Female R/A SMT Type 4P | USB_CON | 2
24V 2A 1812 | | F1 | 1812 _R | FUSE 1812 | 1
INA219 SOIC8 | | INA1 | SO_8_N | INA219 SOIC8 | 1
LED | | L1, L2, L4 | LED_0603_neg | LED | 3
4.7uH/3A | | L3 | INDUCTOR_7mm | INDUCTOR | 1
OLED 0.91INCH | | OLED1 | OLED 0.91INCH | OLED 0.91INCH | 1
SI2302 | N-Channel 20V 2.6A _Ta_ 710mW _Ta_ Surface Mount SOT-23-3 _TO-236_ | Q1, Q2 | SOT23 | SI2302 | 2
4.7K | | R1, R2 | 0603 | RES | 2
0.1R 1% 2512 | | R3 | SHUNT RESISTOR | RES | 1
330R | | R4, R9 | 0603 | RES | 2
36R | | R5, R10 | 1812 _R | RES | 2
2K | | R6 | 0603 | RES | 1
100R | | R7, R11 | 0603 | RES | 2
100K | | R8, R14 | 0603 | RES | 2
10K | | R12, R13 | 0603 | RES | 2
68K | | R15 | 0603 | RES | 1
5K1 | | R16 | 0603 | RES | 1
15K | | R17 | 0603 | RES | 1
1K | | R18 | 0603 | RES | 1
0E | | R19, R20 | 0603 | RES | 2
SWITCH | | SW1 | SWITCH_ON/OFF_3A MP | SWITCH_SLIDE_ON/O FF | 1
AO4406A | | U1, U3, U4, U7, U8, U9 | SO_8_N | AO4406A | 6
HY2213-BB3A | | U2, U6 | SOT-23-6 | HY2213-BB3A | 2
HY2120-OB | | U5 | SOT-23-6 | HY2120-OB | 1
APW7313 | APW7313 DC-DC Converters RoHS SOP-8 PACKAGE | U10 | SOP-8P | APW7313 | 1

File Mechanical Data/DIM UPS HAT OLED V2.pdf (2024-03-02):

SIZE:; SHEET:; DWG NO:; TITLE:; DRAWNBY: DEEPAK SINGH; Realistic View; UPS HAT V2

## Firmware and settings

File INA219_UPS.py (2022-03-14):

'''
The INA219 is a current shunt and power monitor with an I2C- or SMBUS-compatible interface.
The device monitors both shunt voltage drop and bus supply voltage, with programmable conversion times and filtering.
The INA219 operates from –40°C to 125°C.
'''
from serial import SerialException
from oled_091 import SSD1306
from time import sleep
from os import path
import smbus
import time


DIR_PATH = path.abspath(path.dirname(__file__))
DefaultFont = path.join(DIR_PATH, "Fonts/GothamLight.ttf")

def info_print():
    oled_display.DirImage(path.join(DIR_PATH, "Images/SB.png"))
    oled_display.DrawRect()
    oled_display.ShowImage()
    sleep(2)

oled_display = SSD1306()
info_print()

_REG_CONFIG                 = 0x00 # Config Register (R/W)

_REG_SHUNTVOLTAGE           = 0x01 # SHUNT VOLTAGE REGISTER (R)

_REG_BUSVOLTAGE             = 0x02 # BUS VOLTAGE REGISTER (R)

_REG_POWER                  = 0x03 # POWER REGISTER (R)

_REG_CURRENT                = 0x04 # CURRENT REGISTER (R)

_REG_CALIBRATION            = 0x05 # CALIBRATION REGISTER (R/W)

class Bus_Voltage_Range:
    """Constants for ``bus_voltage_range``"""
    RANGE_16V               = 0x00      # set bus voltage range to 16V
    RANGE_32V               = 0x01      # set bus voltage range to 32V (default)

class Gain:
    """Constants for ``gain``"""
    DIV_1_40MV              = 0x00      # shunt prog. gain set to  1, 40 mV range
    DIV_2_80MV              = 0x01      # shunt prog. gain set to /2, 80 mV range
    DIV_4_160MV             = 0x02      # shunt prog. gain set to /4, 160 mV range
    DIV_8_320MV             = 0x03      # shunt prog. gain set to /8, 320 mV range

class ADC_Resolution:
    """Constants for ``bus_adc_resolution`` or ``shunt_adc_resolution``"""
    ADCRES_9BIT_1S          = 0x00      #  9bit,   1 sample,     84us
    ADCRES_10BIT_1S         = 0x01      # 10bit,   1 sample,    148us
    ADCRES_11BIT_1S         = 0x02      # 11 bit,  1 sample,    276us
    ADCRES_12BIT_1S         = 0x03      # 12 bit,  1 sample,    532us
    ADCRES_12BIT_2S         = 0x09      # 12 bit,  2 samples,  1.06ms
    ADCRES_12BIT_4S         = 0x0A      # 12 bit,  4 samples,  2.13ms
    ADCRES_12BIT_8S         = 0x0B      # 12bit,   8 samples,  4.26ms
    ADCRES_12BIT_16S        = 0x0C      # 12bit,  16 samples,  8.51ms
    ADCRES_12BIT_32S        = 0x0D      # 12bit,  32 samples, 17.02ms
    ADCRES_12BIT_64S        = 0x0E      # 12bit,  64 samples, 34.05ms
    ADCRES_12BIT_128S       = 0x0F      # 12bit, 128 samples, 68.10ms

class Mode:
    """Constants for ``mode``"""
    POWERDOW                = 0x00      # power down
    SVOLT_TRIGGERED         = 0x01      # shunt voltage triggered
    BVOLT_TRIGGERED         = 0x02      # bus voltage triggered
    SANDBVOLT_TRIGGERED     = 0x03      # shunt and bus voltage triggered
    ADCOFF                  = 0x04      # ADC off
    SVOLT_CONTINUOUS        = 0x05      # shunt voltage continuous
    BVOLT_CONTINUOUS        = 0x06      # bus voltage continuous
    SANDBVOLT_CONTINUOUS    = 0x07      # shunt and bus voltage continuous


class INA219:
    def __init__(self, i2c_bus=1, addr=0x40):
        self.bus = smbus.SMBus(i2c_bus);
        self.addr = addr

        # Set chip to known config values to start
        self._cal_value = 0
        self._current_lsb = 0
        self._power_lsb = 0
        self.calibration()

    def read(self,address):
        data = self.bus.read_i2c_block_data(self.addr, address, 2)
        return ((data[0] * 256 ) + data[1])

    def write(self,address,data):
        temp = [0,0]
        temp[1] = data & 0xFF
        temp[0] =(data & 0xFF00) >> 8
        self.bus.write_i2c_block_data(self.addr,address,temp)


    def calibration(self): # set calibration 32V ,2A
        """Configures to INA219 to be able to measure up to 32V and 2A of current. Counter
           overflow occurs at 3.2A.
           ..note :: These calculations assume a 0.1 shunt ohm resistor is present
        """

        self._current_lsb = 0.1  # Current LSB = 100uA per bit
        
        self._cal_value = 4096
        
        self._power_lsb = 0.002  # Power LSB = 2mW per bit

        

        # Set Calibration register to 'Cal' calculated above
        self.write(_REG_CALIBRATION,self._cal_value)

        # Set Config register to take into account the settings above
        self.bus_voltage_range = Bus_Voltage_Range.RANGE_32V
        self.gain = Gain.DIV_8_320MV
        self.bus_adc_resolution = ADC_Resolution.ADCRES_12BIT_32S
        self.shunt_adc_resolution = ADC_Resolution.ADCRES_12BIT_32S
        self.mode = Mode.SANDBVOLT_CONTINUOUS
        self.config = self.bus_voltage_range << 13 | \
                      self.gain << 11 | \
                      self.bus_adc_resolution << 7 | \
                      self.shunt_adc_resolution << 3 | \
                      self.mode
        self.write(_REG_CONFIG,self.config)

    def Shunt_Voltage(self): # shunt voltage in milli volt
        self.write(_REG_CALIBRATION,self._cal_value)
        value = self.read(_REG_SHUNTVOLTAGE)
        if value > 32767:
            value -= 65535
        return value * 0.01

    def Current(self): # current in milli amp
        value = self.read(_REG_CURRENT)
        if value > 32767:
            value -= 65535
        return value * self._current_lsb

    def Power(self):
        self.write(_REG_CALIBRATION,self._cal_value)
        value = self.read(_REG_POWER)
        if value > 32767:
            value -= 65535
        return value * self._power_lsb
    
    def Bus_Voltage(self):
        self.write(_REG_CALIBRATION,self._cal_value)
        self.read(_REG_BUSVOLTAGE)
        return (self.read(_REG_BUSVOLTAGE) >> 3) * 0.004


        
# Create an INA219 instance.
ina219 = INA219(addr=0x42)

while True:
        bus_voltage = ina219.Bus_Voltage()             # voltage on V- (load side)
        shunt_voltage = ina219.Shunt_Voltage() / 1000 # voltage between V+ and V- across the shunt
        current = ina219.Current()                   # current in mA
        power = ina219.Power()                        # power in W
        p = (bus_voltage - 6)/2.4*100
        if(p > 100):p = 100
        if(p < 0):p = 0


        print("Load Voltage:  {:6.3f} V".format(bus_voltage))
        print("Current:       {:9.6f} A".format(current/1000))
        print("Power:         {:6.3f} W".format(power))
        print("Percent:       {:3.1f}%".format(p))
        print("")

        # print readings in oled display
        oled_display.PrintText("Load Voltage= {:6.3f} V".format(bus_voltage),cords=(0, 0), FontSize=10)
        oled_display.PrintText("Current = {:9.6f} A".format(current/1000),cords=(0,8), FontSize=10)
        oled_display.PrintText("Power = {:6.3f} W".format(power),cords=(0,16), FontSize=10)
        oled_display.PrintText("Percent = {:3.1f}%".format(p),cords=(0,24), FontSize=10)
        oled_display.ShowImage()

        time.sleep(2)
